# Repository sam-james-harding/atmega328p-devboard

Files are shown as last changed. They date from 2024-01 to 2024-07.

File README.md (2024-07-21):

# atmega328p-devboard

This is my own custom development board, made for the ATmega328P. I created this both as learning experience (in PCB design and in soldering SMD components), and as a practical device to assist in prototyping.

## Features
- USB connection providing power and allowing serial communication
  - Micro-USB B for Rev. 1
  - USB C for Rev. 2
- USB-to-UART functionality via the MCP2221A IC
- Regulated 3.3V supply: power, supplied either through the USB connection or the VIN pin, can be supplied at up to 6V (using the MCP1825 voltage regulator)
- Switches for both power and USB-to-serial functionality
- LEDs to show power status and serial communication
- 16MHz crystal
- Reset button
- 6-pin ISP header (i.e. for AVRISP or the Pololu AVR programmer)

## Images

### Rev. 1
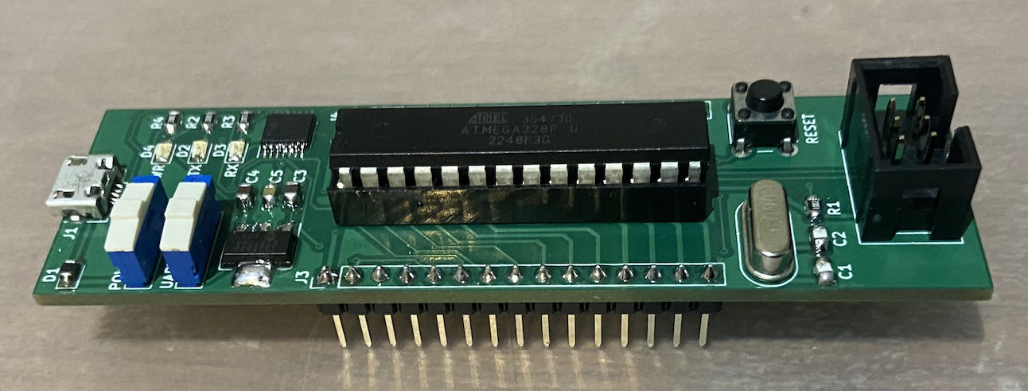
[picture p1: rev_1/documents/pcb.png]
PCB v1 Image


### Rev. 2
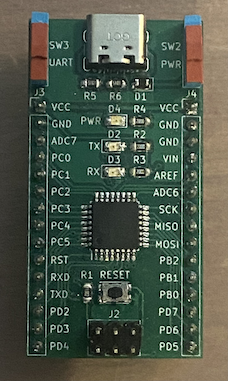
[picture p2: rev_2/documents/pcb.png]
PCB v2 Image


## Drawings
- [Schematic](https://github.com/sam-james-harding/atmega328p-devboard/blob/main/rev_1/documents/Schematic.pdf)
- PCB [front](https://github.com/sam-james-harding/atmega328p-devboard/blob/main/rev_1/documents/PCB%20Front.pdf)
and [back](https://github.com/sam-james-harding/atmega328p-devboard/blob/main/rev_1/documents/PCB%20Back.pdf)

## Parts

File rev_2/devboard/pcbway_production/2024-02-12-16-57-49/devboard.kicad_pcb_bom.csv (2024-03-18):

designator | quantity | value | pack | mpn | mount_type
C1, C2 | 2 | 10pF | C_0805_2012Metric_Pad1.18x1.45mm_HandSolder |  | smt
C3, C4 | 2 | 4.7uF | C_0805_2012Metric_Pad1.18x1.45mm_HandSolder |  | smt
C5 | 1 | 1uF | C_0805_2012Metric_Pad1.18x1.45mm_HandSolder |  | smt
D1 | 1 | D_Schottky | D_0805_2012Metric_Pad1.15x1.40mm_HandSolder |  | smt
D2, D3 | 2 | YELLOW | LED_0805_2012Metric_Pad1.15x1.40mm_HandSolder |  | smt
D4 | 1 | LED_RED | LED_0805_2012Metric_Pad1.15x1.40mm_HandSolder |  | smt
J1 | 1 | USB_C_Receptacle_USB2.0_16P | USB_C_Receptacle_GCT_USB4105-xx-A_16P_TopMnt_Horizontal |  | smt
J2 | 1 | AVR-ISP-6 | PinHeader_2x03_P2.54mm_Vertical |  | tht
J3, J4 | 2 | Conn_01x15_Pin | PinHeader_1x15_P2.54mm_Vertical |  | tht
R1 | 1 | 10K | R_0805_2012Metric_Pad1.20x1.40mm_HandSolder |  | smt
R2, R3, R4 | 3 | 470R | R_0805_2012Metric_Pad1.20x1.40mm_HandSolder |  | smt
R5, R6 | 2 | 5K1 | R_0805_2012Metric_Pad1.20x1.40mm_HandSolder |  | smt
SW1 | 1 | Pushbutton | SW_Push_1P1T_NO_CK_KMR2 |  | smt
SW2, SW3 | 2 | SPDT | slide_switch |  | tht
U1 | 1 | ATmega328P-A | TQFP-32_7x7mm_P0.8mm |  | smt
U2 | 1 | MCP2221A-I/ST | TSSOP-14_4.4x5mm_P0.65mm |  | smt
U3 | 1 | MCP1825S | SOT-223-3_TabPin2 |  | smt
Y1 | 1 | Crystal_GND24 | Crystal_SMD_3225-4Pin_3.2x2.5mm_HandSoldering |  | smt

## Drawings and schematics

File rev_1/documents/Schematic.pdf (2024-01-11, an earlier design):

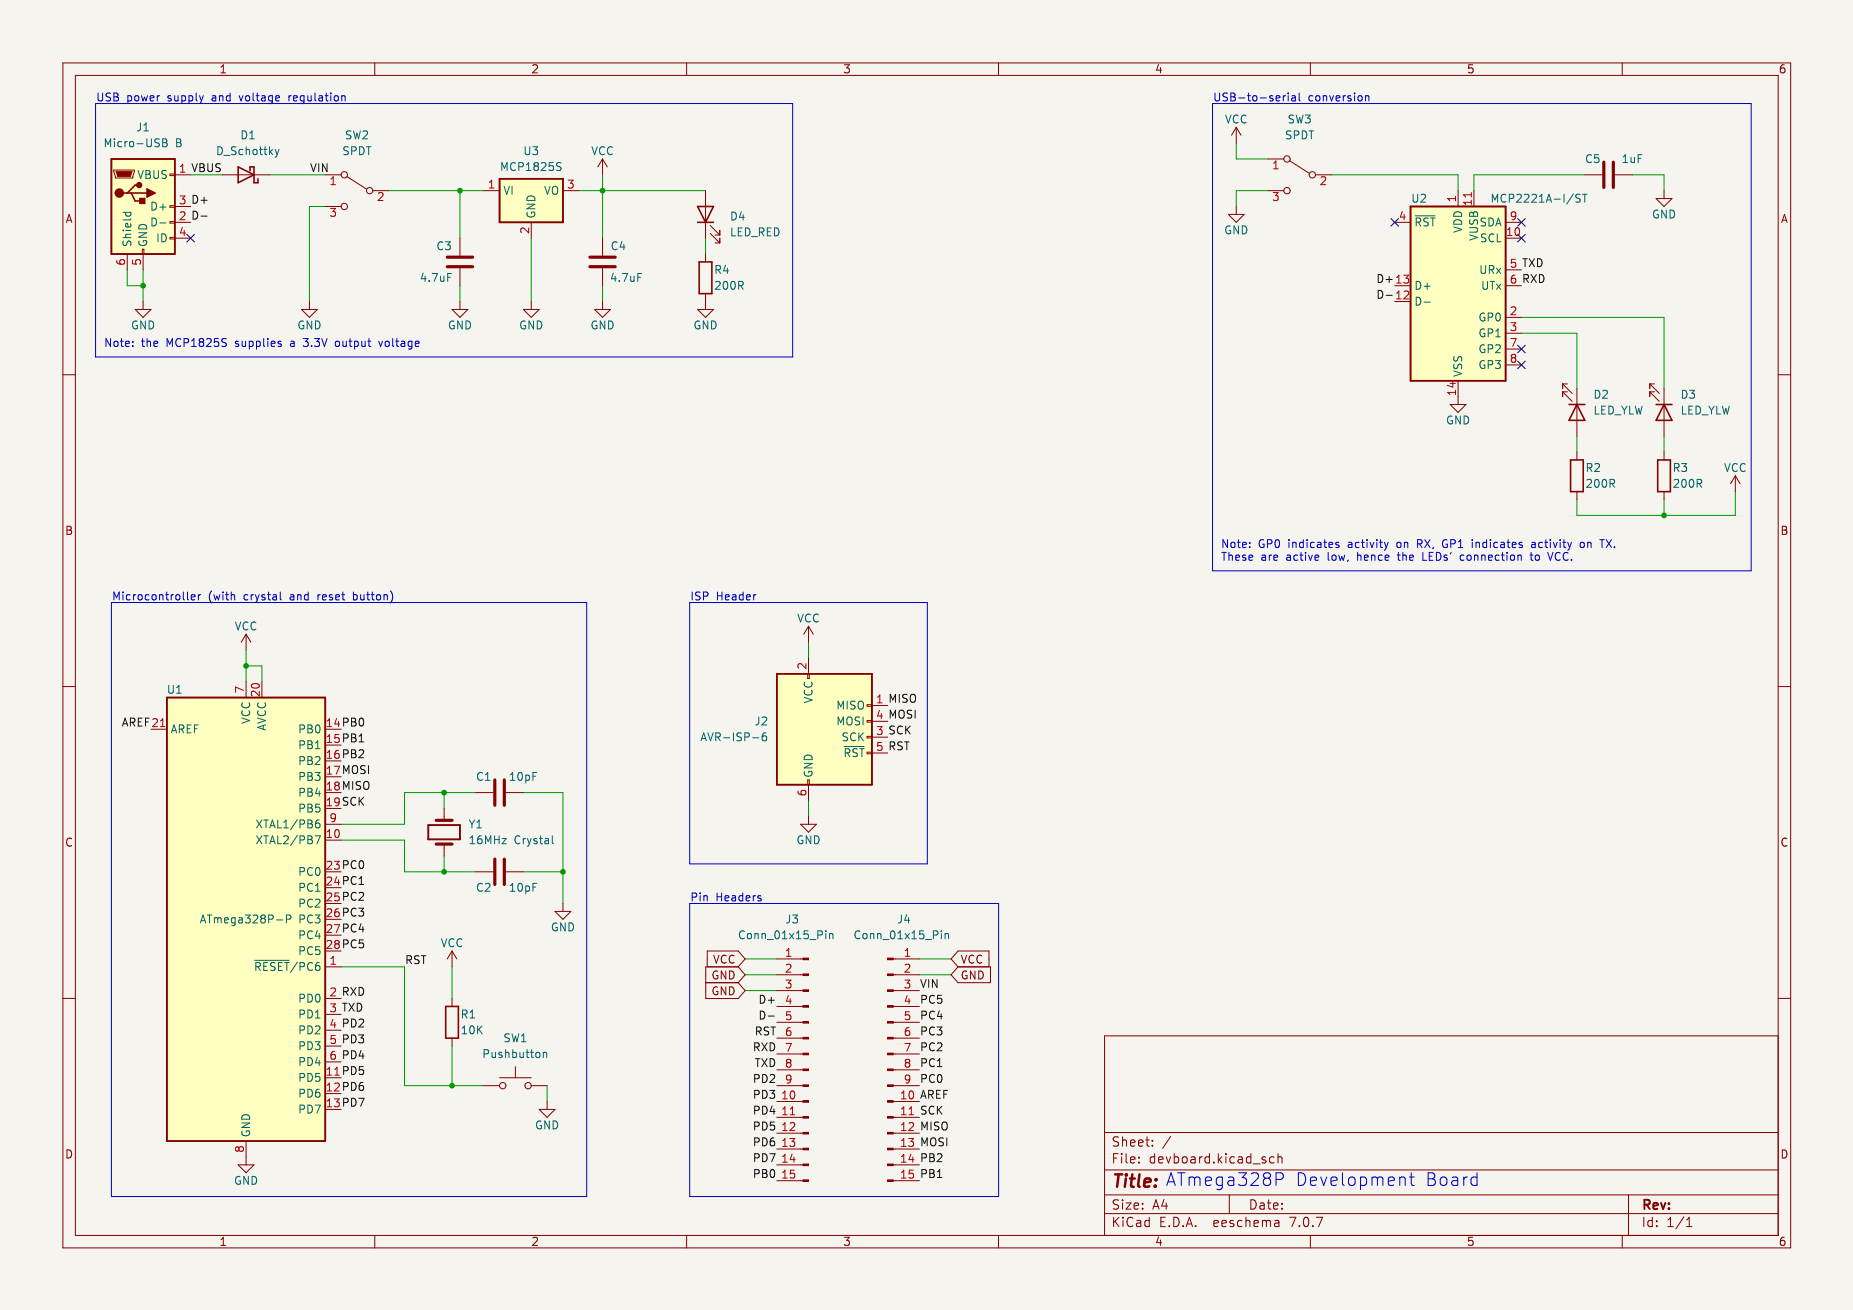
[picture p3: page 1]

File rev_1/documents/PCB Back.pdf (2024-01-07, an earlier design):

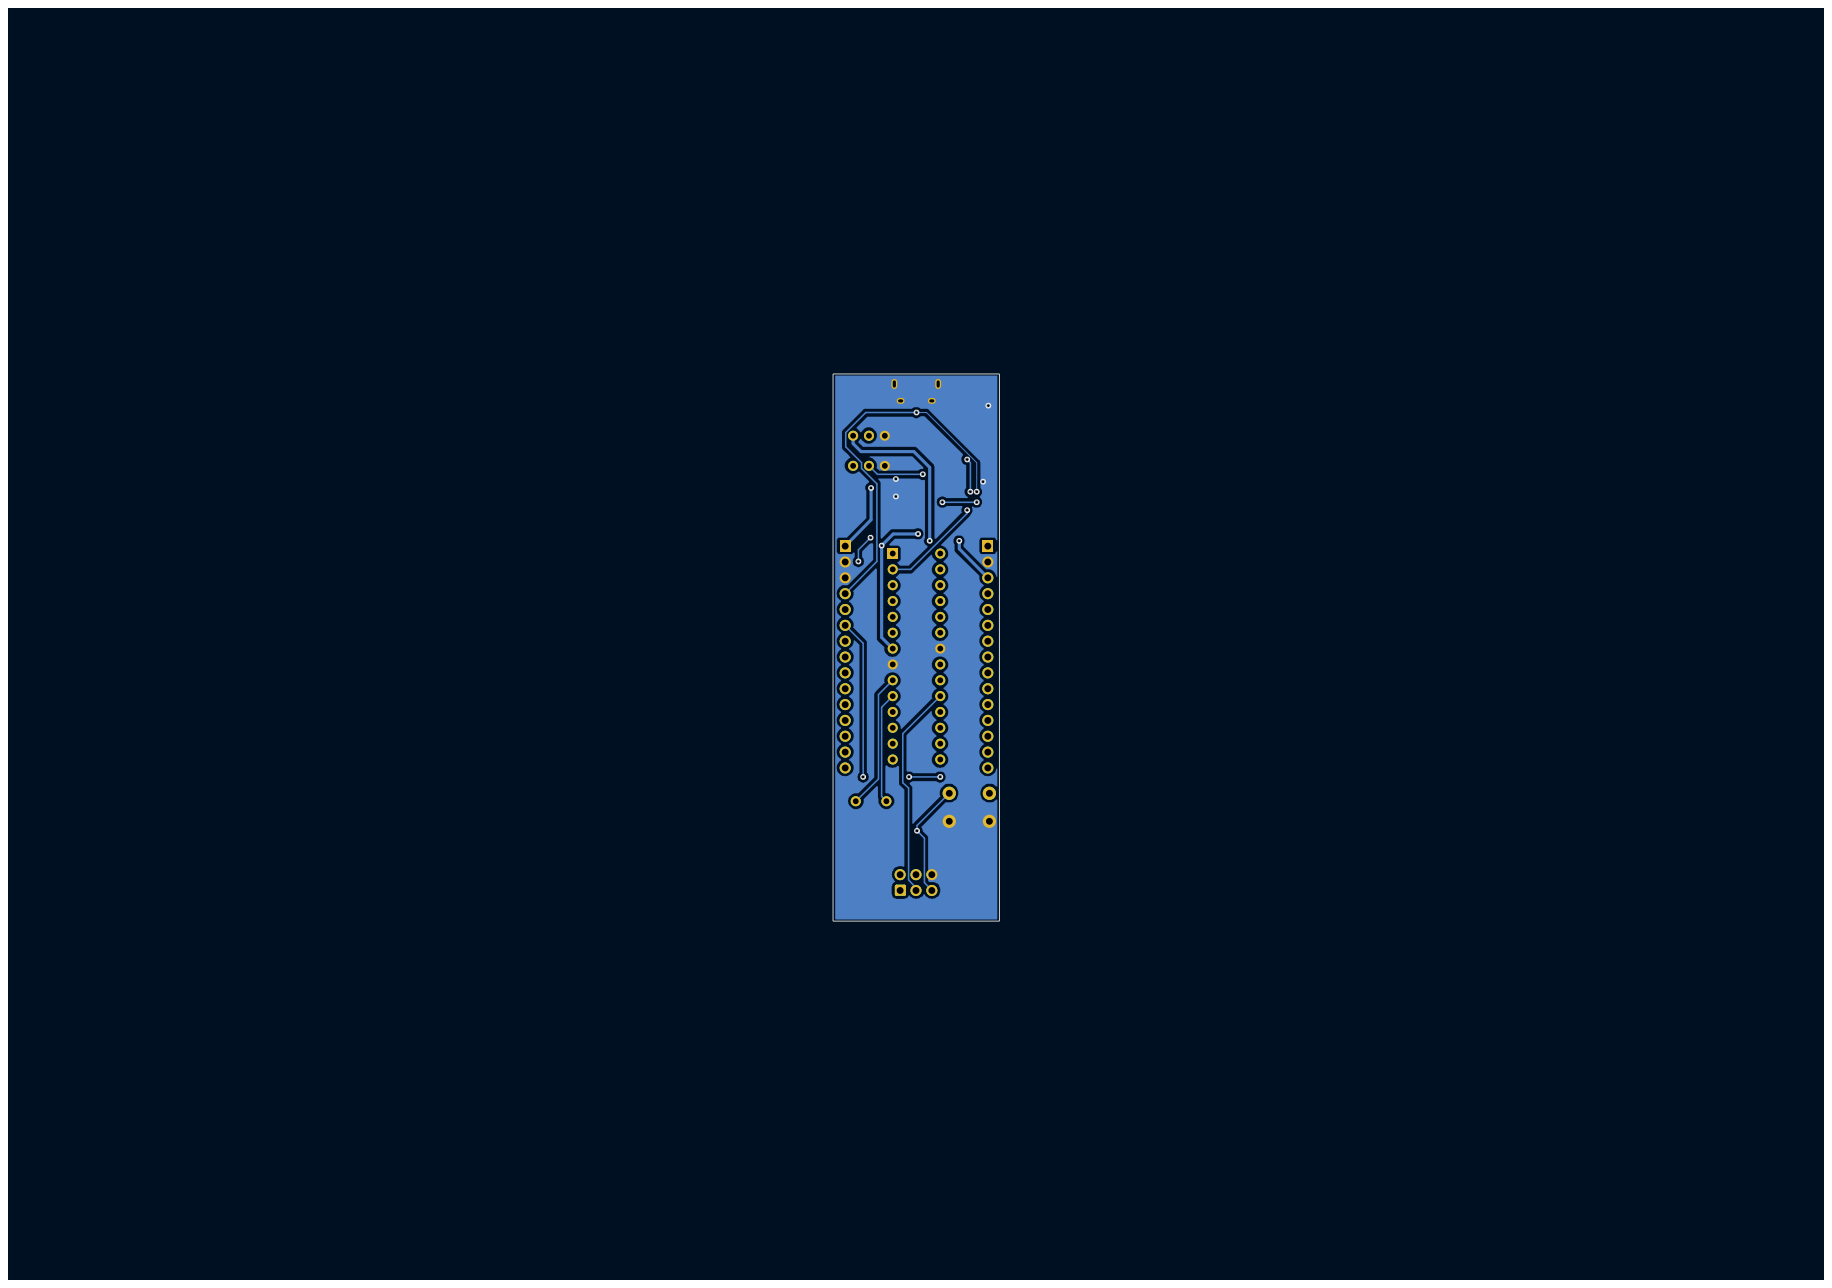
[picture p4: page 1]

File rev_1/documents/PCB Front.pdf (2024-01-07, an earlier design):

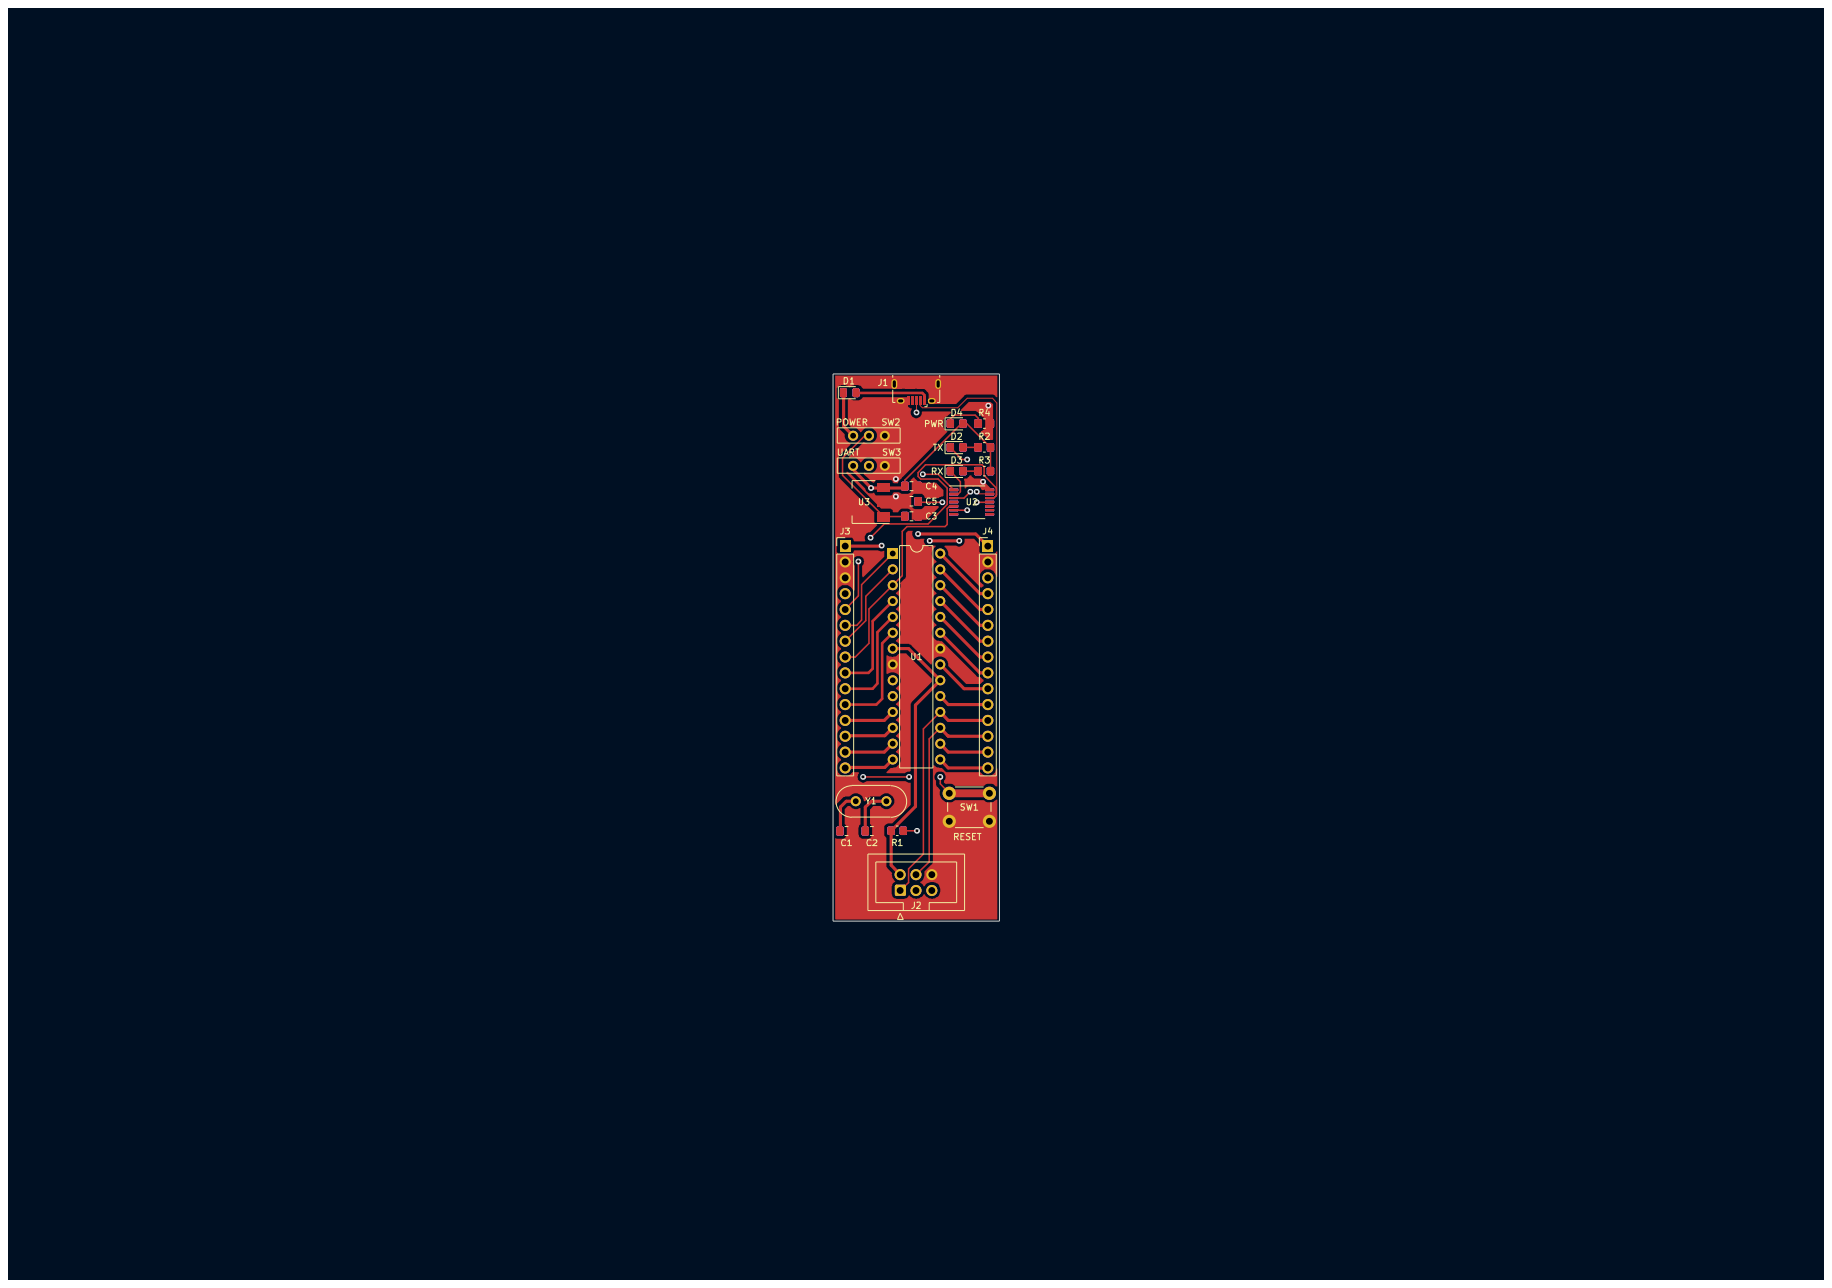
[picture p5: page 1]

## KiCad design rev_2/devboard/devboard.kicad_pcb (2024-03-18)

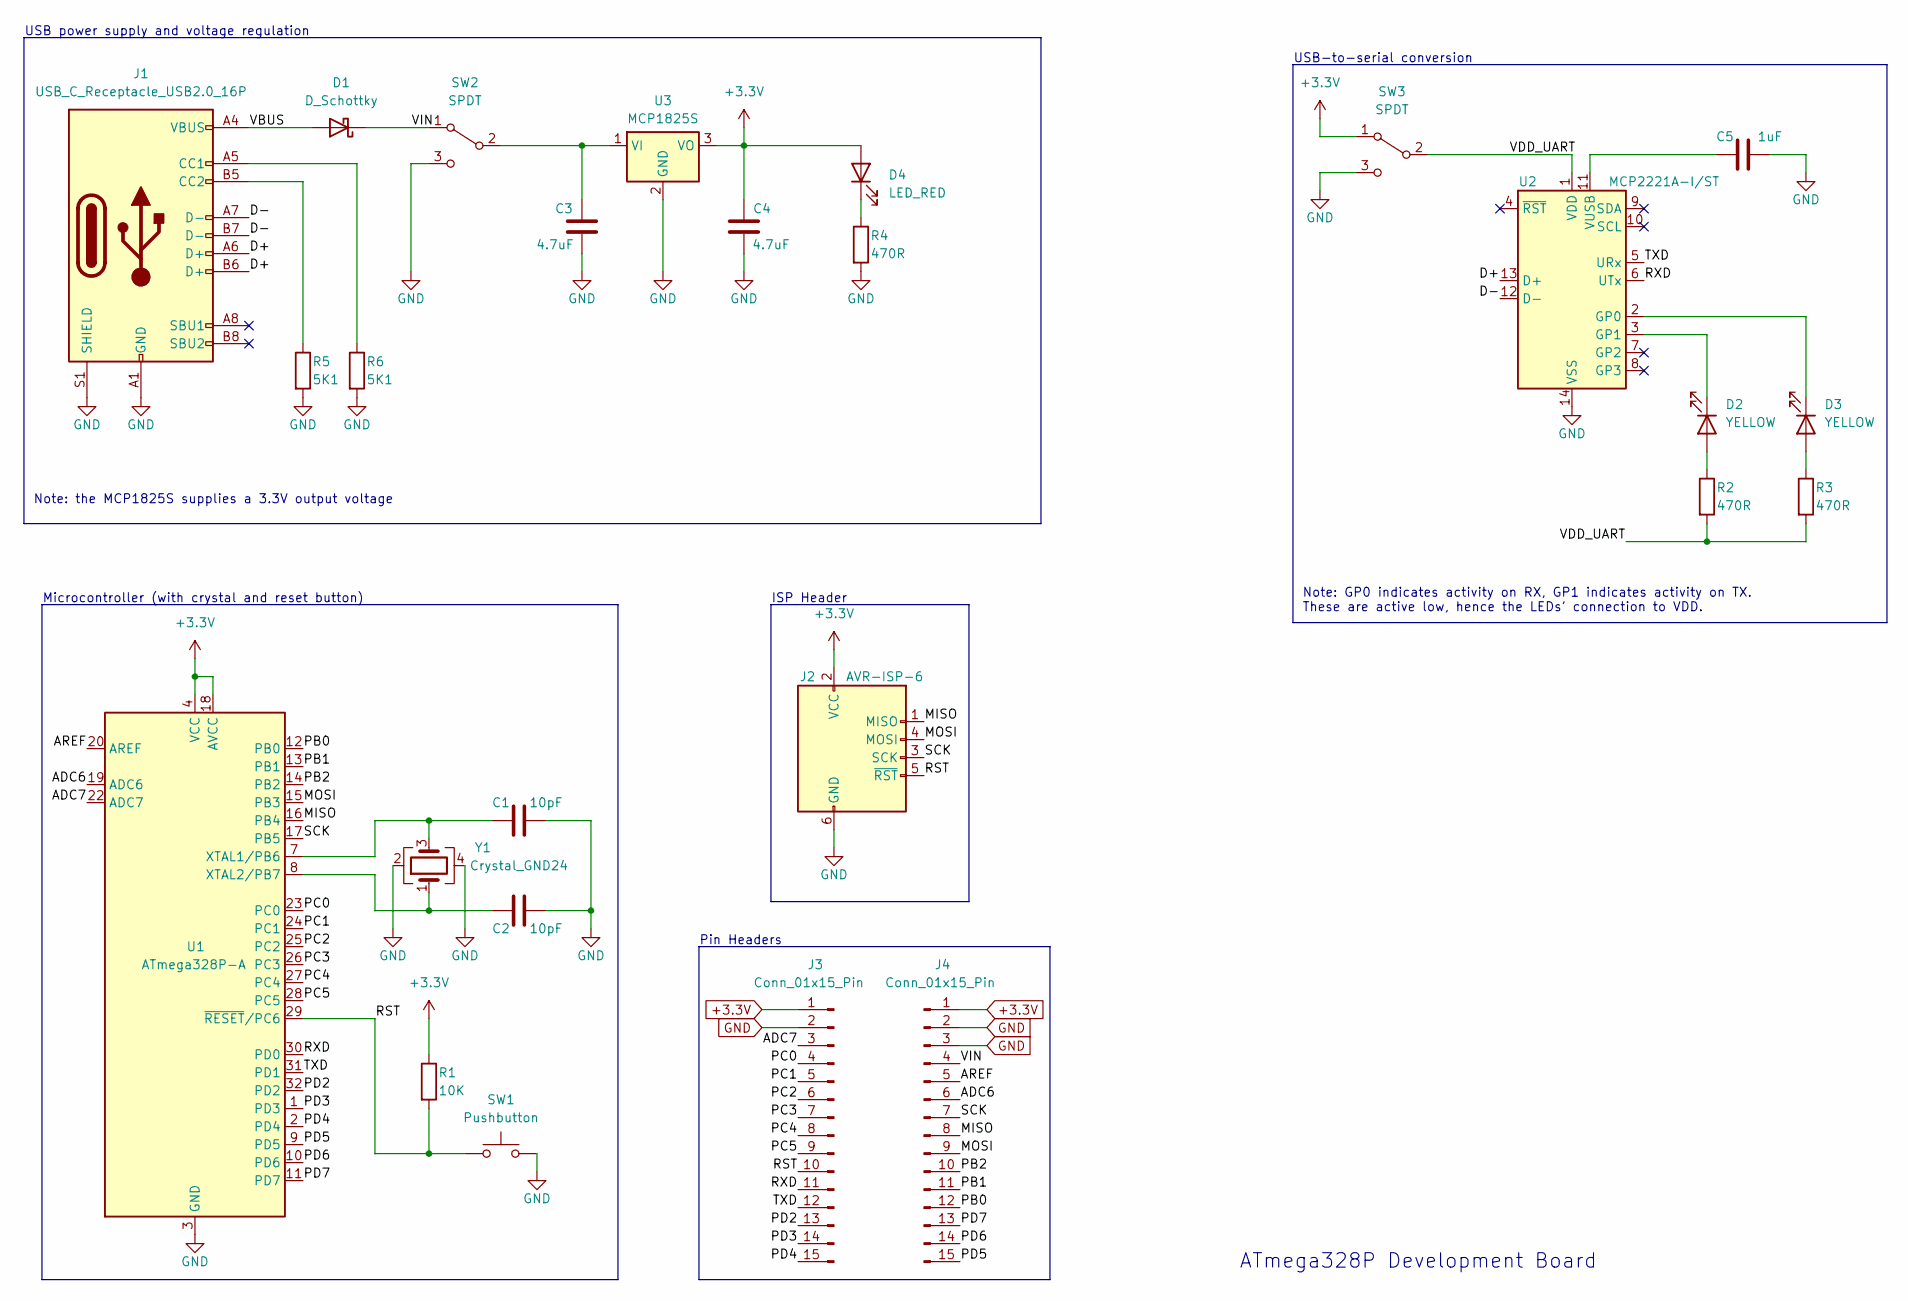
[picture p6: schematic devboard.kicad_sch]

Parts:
C1, C2: 10pF; C_0805_2012Metric_Pad1.18x1.45mm_HandSolder
C3, C4: 4.7uF; C_0805_2012Metric_Pad1.18x1.45mm_HandSolder
C5: 1uF; C_0805_2012Metric_Pad1.18x1.45mm_HandSolder; Mfr Part # C0805C105K3RACTU
D1: D_Schottky; D_0805_2012Metric_Pad1.15x1.40mm_HandSolder
D2, D3: YELLOW; LED_0805_2012Metric_Pad1.15x1.40mm_HandSolder
D4: LED_RED; LED_0805_2012Metric_Pad1.15x1.40mm_HandSolder
J1: USB_C_Receptacle_USB2.0_16P; USB_C_Receptacle_GCT_USB4105-xx-A_16P_TopMnt_Horizontal
J2: AVR-ISP-6; PinHeader_2x03_P2.54mm_Vertical
J3, J4: Conn_01x15_Pin; PinHeader_1x15_P2.54mm_Vertical
R1: 10K; R_0805_2012Metric_Pad1.20x1.40mm_HandSolder
R2, R3, R4: 470R; R_0805_2012Metric_Pad1.20x1.40mm_HandSolder
R5, R6: 5K1; R_0805_2012Metric_Pad1.20x1.40mm_HandSolder
SW1: Pushbutton; SW_Push_1P1T_NO_CK_KMR2
SW2, SW3: SPDT; slide_switch
U1: ATmega328P-A; TQFP-32_7x7mm_P0.8mm
U2: MCP2221A-I/ST; TSSOP-14_4.4x5mm_P0.65mm; Mfr Part # MCP2221A-I/ST
U3: MCP1825S; SOT-223-3_TabPin2
Y1: Crystal_GND24; Crystal_SMD_3225-4Pin_3.2x2.5mm_HandSoldering

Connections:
+3.3V: C4.2, D4.2 (A), J2.2 (VCC), J3.1, J4.1, R1.1, SW3.1 (A), U1.4 (VCC), U1.6 (VCC), U1.18 (AVCC), U3.3 (VO)
/ADC6: J4.6, U1.19 (ADC6)
/ADC7: J3.3, U1.22 (ADC7)
/AREF: J4.5, U1.20 (AREF)
/D+: J1.A6 (D+), J1.B6 (D+), U2.13 (D+)
/D-: J1.A7 (D-), J1.B7 (D-), U2.12 (D-)
/MISO: J2.1 (MISO), J4.8, U1.16 (PB4)
/MOSI: J2.4 (MOSI), J4.9, U1.15 (PB3)
/PB0: J4.12, U1.12 (PB0)
/PB1: J4.11, U1.13 (PB1)
/PB2: J4.10, U1.14 (PB2)
/PC0: J3.4, U1.23 (PC0)
/PC1: J3.5, U1.24 (PC1)
/PC2: J3.6, U1.25 (PC2)
/PC3: J3.7, U1.26 (PC3)
/PC4: J3.8, U1.27 (PC4)
/PC5: J3.9, U1.28 (PC5)
/PD2: J3.13, U1.32 (PD2)
/PD3: J3.14, U1.1 (PD3)
/PD4: J3.15, U1.2 (PD4)
/PD5: J4.15, U1.9 (PD5)
/PD6: J4.14, U1.10 (PD6)
/PD7: J4.13, U1.11 (PD7)
/RST: J2.5 (~RST), J3.10, R1.2, SW1.1, U1.29 (~RESET/PC6)
/RXD: J3.11, U1.30 (PD0), U2.6 (UTx)
/SCK: J2.3 (SCK), J4.7, U1.17 (PB5)
/TXD: J3.12, U1.31 (PD1), U2.5 (URx)
/VBUS: D1.2 (A), J1.A4 (VBUS), J1.A9 (VBUS), J1.B4 (VBUS), J1.B9 (VBUS)
/VDD_UART: R2.2, R3.2, SW3.2 (B), U2.1 (VDD)
/VIN: D1.1 (K), J4.4, SW2.1 (A)
GND: C1.1, C2.1, C3.2, C4.1, C5.1, J1.A1 (GND), J1.A12 (GND), J1.B1 (GND), J1.B12 (GND), J1.S1 (SHIELD), J2.6 (GND), J3.2, J4.2, J4.3, R4.2, R5.2, R6.2, SW1.2, SW2.3 (C), SW3.3 (C), U1.3 (GND), U1.5 (GND), U1.21 (GND), U2.14 (VSS), U3.2 (GND), Y1.2, Y1.4
unnamed: D2.2 (A), R2.1
unnamed: D2.1 (K), U2.3 (GP1)
unnamed: D3.2 (A), R3.1
unnamed: D3.1 (K), U2.2 (GP0)
unnamed: D4.1 (K), R4.1
unnamed: J1.A5 (CC1), R6.1
unnamed: J1.B5 (CC2), R5.1
unnamed: C3.1, SW2.2 (B), U3.1 (VI)
unnamed: C1.2, U1.7 (XTAL1/PB6), Y1.3
unnamed: C2.2, U1.8 (XTAL2/PB7), Y1.1
unnamed: C5.2, U2.11 (VUSB)

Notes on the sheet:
ISP Header
Pin Headers
USB-to-serial conversion
ATmega328P Development Board
Note: the MCP1825S supplies a 3.3V output voltage
Microcontroller (with crystal and reset button)
Note: GP0 indicates activity on RX, GP1 indicates activity on TX. These are active low, hence the LEDs' connection to VDD.
USB power supply and voltage regulation

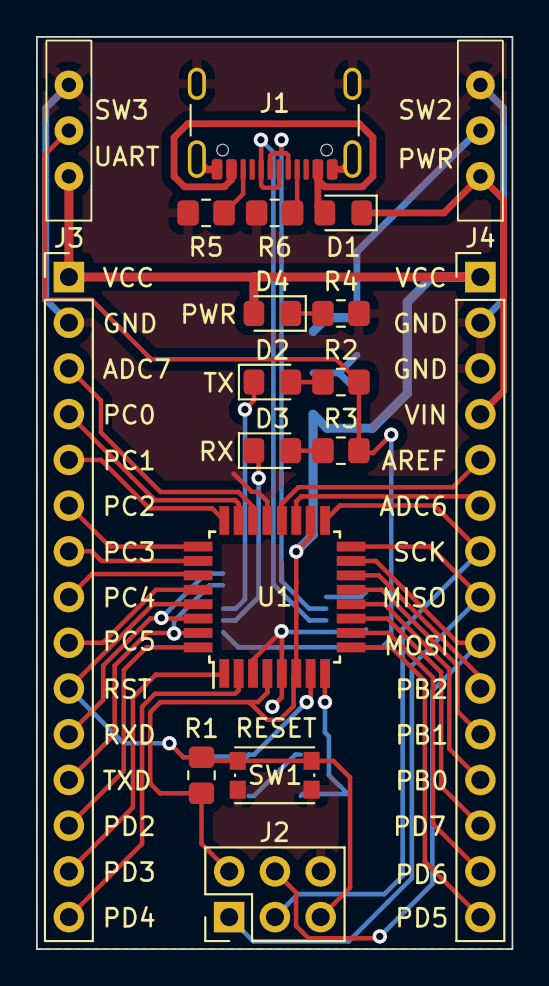
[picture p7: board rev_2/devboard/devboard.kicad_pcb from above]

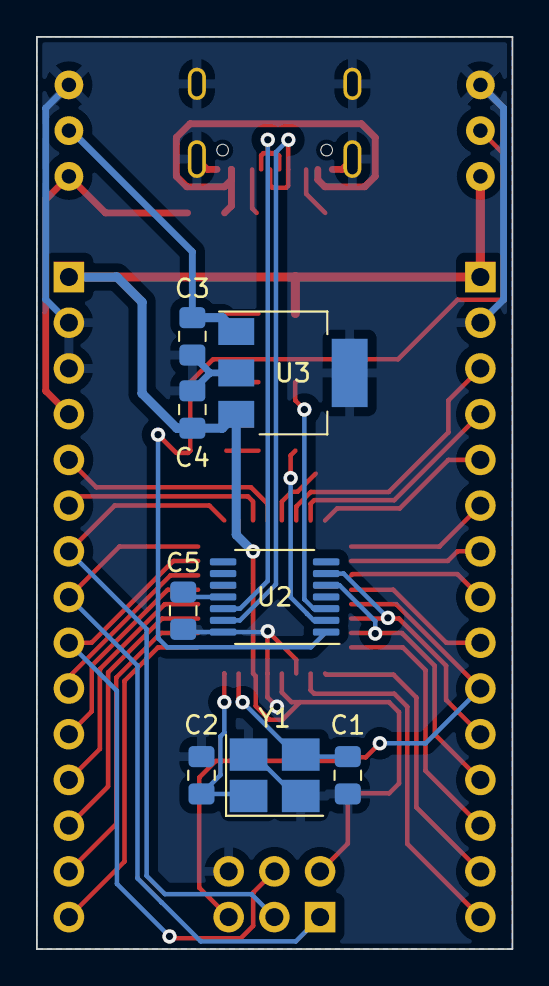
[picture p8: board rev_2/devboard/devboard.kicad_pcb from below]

Board: 2 copper layers, 26.4 x 50.7 mm, 26 parts (8 on the bottom side), 42 nets.

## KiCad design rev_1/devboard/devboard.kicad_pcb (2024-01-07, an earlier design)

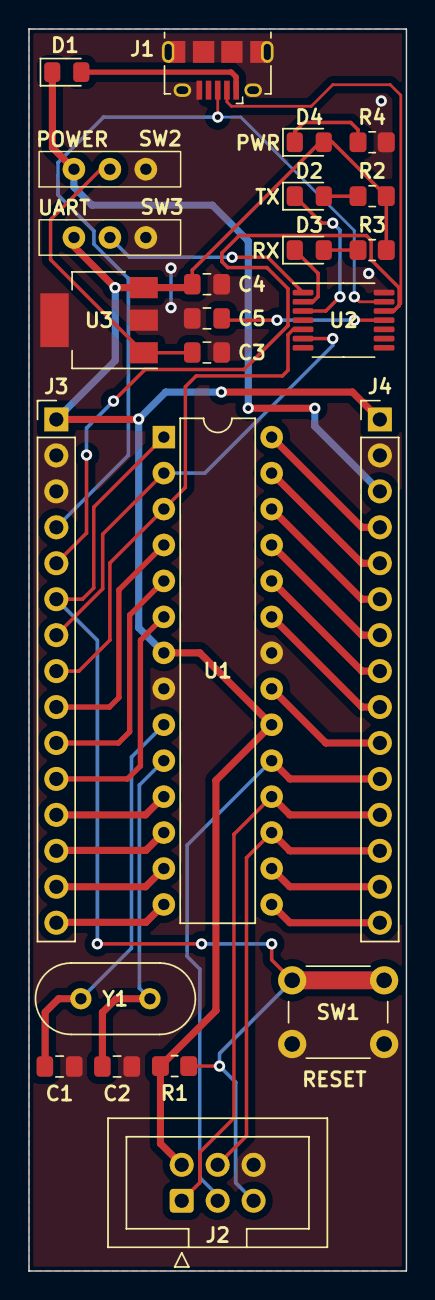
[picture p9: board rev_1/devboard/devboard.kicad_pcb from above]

Board: 2 copper layers, 26.7 x 87.8 mm, 24 parts (0 on the bottom side), 38 nets.

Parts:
C1, C2: 10pF; C_0805_2012Metric_Pad1.18x1.45mm_HandSolder
C3, C4: 4.7μF; C_0805_2012Metric_Pad1.18x1.45mm_HandSolder
C5: 1μF; C_0805_2012Metric_Pad1.18x1.45mm_HandSolder
D1: D_Schottky; D_0805_2012Metric_Pad1.15x1.40mm_HandSolder
D2: LED_TX; LED_0805_2012Metric_Pad1.15x1.40mm_HandSolder
D3: LED_RX; LED_0805_2012Metric_Pad1.15x1.40mm_HandSolder
D4: LED; LED_0805_2012Metric_Pad1.15x1.40mm_HandSolder
J1: USB_B_Micro; USB_Micro-B_Amphenol_10118194_Horizontal
J2: AVR-ISP-6; IDC-Header_2x03_P2.54mm_Vertical
J3, J4: Conn_01x15_Pin; PinHeader_1x15_P2.54mm_Vertical
R1: 10KΩ; R_0805_2012Metric_Pad1.20x1.40mm_HandSolder
R2, R3, R4: 200Ω; R_0805_2012Metric_Pad1.20x1.40mm_HandSolder
SW1: Pushbutton; SW_PUSH_6mm
SW2, SW3: SW_SPDT; slide_switch
U1: ATmega328P-P; DIP-28_W7.62mm
U2: MCP2221AxST; TSSOP-14_4.4x5mm_P0.65mm
U3: MCP1825S; SOT-223-3_TabPin2
Y1: Crystal; Crystal_HC49-U_Vertical

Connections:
/AREF: J4.10, U1.21 (AREF)
/D+: J1.3 (D+), J3.4, U2.13 (D+)
/D-: J1.2 (D-), J3.5, U2.12 (D-)
/MISO: J2.1 (MISO), J4.12, U1.18 (PB4)
/MOSI: J2.4 (MOSI), J4.13, U1.17 (PB3)
/PB0: J3.15, U1.14 (PB0)
/PB1: J4.15, U1.15 (PB1)
/PB2: J4.14, U1.16 (PB2)
/PC0: J4.9, U1.23 (PC0)
/PC1: J4.8, U1.24 (PC1)
/PC2: J4.7, U1.25 (PC2)
/PC3: J4.6, U1.26 (PC3)
/PC4: J4.5, U1.27 (PC4)
/PC5: J4.4, U1.28 (PC5)
/PD2: J3.9, U1.4 (PD2)
/PD3: J3.10, U1.5 (PD3)
/PD4: J3.11, U1.6 (PD4)
/PD5: J3.12, U1.11 (PD5)
/PD6: J3.13, U1.12 (PD6)
/PD7: J3.14, U1.13 (PD7)
/RST: J2.5 (~RST), J3.6, R1.2, SW1.1, U1.1 (~RESET/PC6)
/RXD: J3.7, U1.2 (PD0), U2.6 (UTx)
/SCK: J2.3 (SCK), J4.11, U1.19 (PB5)
/TXD: J3.8, U1.3 (PD1), U2.5 (URx)
/VBUS: D1.2 (A), J1.1 (VBUS)
/VIN: D1.1 (K), J4.3, SW2.1 (A)
GND: C1.1, C2.1, C3.2, C4.1, C5.1, J1.5 (GND), J1.6 (Shield), J2.6 (GND), J3.2, J3.3, J4.2, R4.2, SW1.2, SW2.3 (C), SW3.3 (C), U1.8 (GND), U1.22 (GND), U2.14 (VSS), U3.2 (GND)
unnamed: D2.2 (A), R2.1
unnamed: D2.1 (K), U2.3 (GP1)
unnamed: D3.2 (A), R3.1
unnamed: D3.1 (K), U2.2 (GP0)
unnamed: D4.1 (K), R4.1
unnamed: C3.1, SW2.2 (B), U3.1 (VI)
unnamed: SW3.2 (B), U2.1 (VDD)
unnamed: C1.2, U1.9 (XTAL1/PB6), Y1.2
unnamed: C2.2, U1.10 (XTAL2/PB7), Y1.1
unnamed: C5.2, U2.11 (VUSB)
VCC: C4.2, D4.2 (A), J2.2 (VCC), J3.1, J4.1, R1.1, R2.2, R3.2, SW3.1 (A), U1.7 (VCC), U1.20 (AVCC), U3.3 (VO)

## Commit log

2024-01-07 Added CAD files and printouts
    [devboard.kicad_pcb, devboard.kicad_sch]
2024-01-07 Revert "Added CAD files and printouts"
    This reverts commit 5d408bc1e87f594881d4da881a5795643422694f.
    [devboard.kicad_pcb, devboard.kicad_sch]
2024-01-11 Minor changes + added BOM
    [BOM.csv, devboard.kicad_sch]
2024-02-02 Changed file structure
    [BOM.csv, devboard.kicad_pcb, devboard.kicad_sch]
2024-02-11 Routed most of rev_2
    [devboard.kicad_pcb, devboard.kicad_sch]
2024-03-18 Finished rev 2
    [devboard-B_Cu.gbr, devboard-B_Mask.gbr, devboard-B_Paste.gbr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]
